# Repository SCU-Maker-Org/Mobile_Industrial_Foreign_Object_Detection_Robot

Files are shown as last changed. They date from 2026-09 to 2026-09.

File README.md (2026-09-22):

# 移动式工业异物检测机器人（履带式）

面向"机器人异物检测专项赛"的履带式自主巡检机器人。机器人在模拟核电站室内巡检环境中完全自主运行，完成对工具类、零件类、杂物类和泄漏物类异物的检测，并提交结构化检测报告。

## 机器人平台

- **底盘形式**：履带式，适应室内复杂地面与局部暗区环境
- **运行方式**：完全自主巡检，无需人工干预
- **导航能力**：支持自主导航与建图，可在赛前基准扫描阶段对场地建模
- **感知传感器**：配备 RGB 相机，可选配深度相机、热成像仪等
- **视觉检测**：基于 YOLO 的异物检测，支持双目视觉进行深度感知与三维定位

## 核心功能

| 功能 | 说明 |
|---|---|
| 自主建图与导航 | 赛前对基准场景建模，比赛中自主规划巡检路径 |
| 异物检出 | 检测工具类、零件类、杂物类、泄漏物类异物 |
| 异物分类 | 按工具类、零件类、杂物类、泄漏物类四类输出 |
| 异物定位 | 输出异物平面位置坐标，支持厘米级定位 |
| 误报控制 | 区分真实异物与设备、管道、地面纹理、阴影等背景干扰 |
| 检测报告 | 输出异物编号、类别、位置坐标、置信度和检测时间 |
| 光照适应 | 适应正常照明与局部暗区两种光照条件 |
| 遮挡适应 | 应对设备柜、管道阀门、电缆槽、基座和遮挡板形成的遮挡关系 |

## 工作流程

```text
基准扫描建图 → 自主巡检 → 异物检测 → 分类与定位 → 生成检测报告

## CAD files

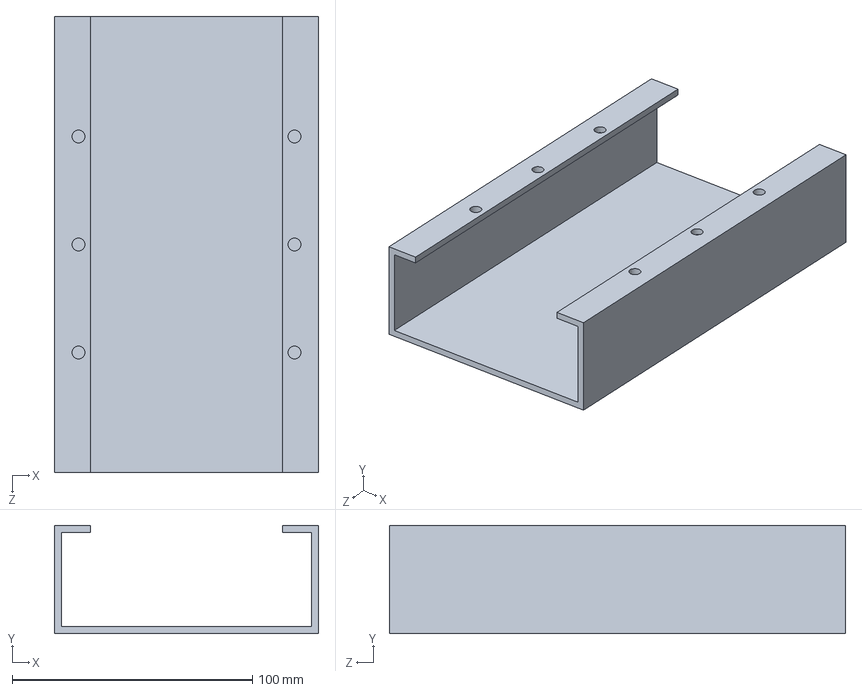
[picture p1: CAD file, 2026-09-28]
3D_Files/solidworks/底盘电池支架.SLDPRT
110.0 x 45.0 x 190.0 mm

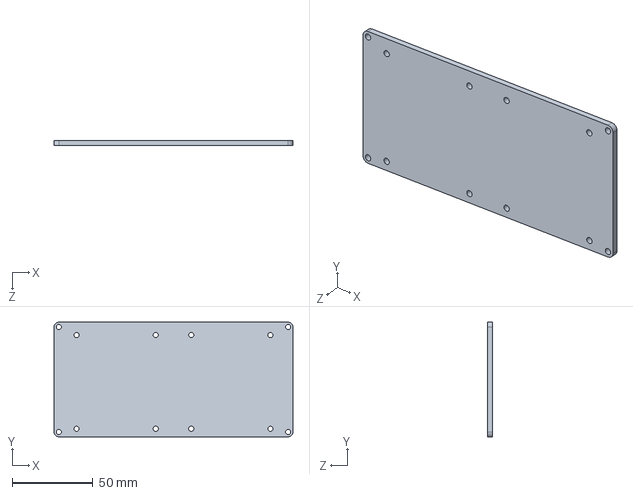
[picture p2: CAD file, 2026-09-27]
3D_Files/solidworks/树莓派和香橙派支架.SLDPRT
148.0 x 71.0 x 3.00 mm

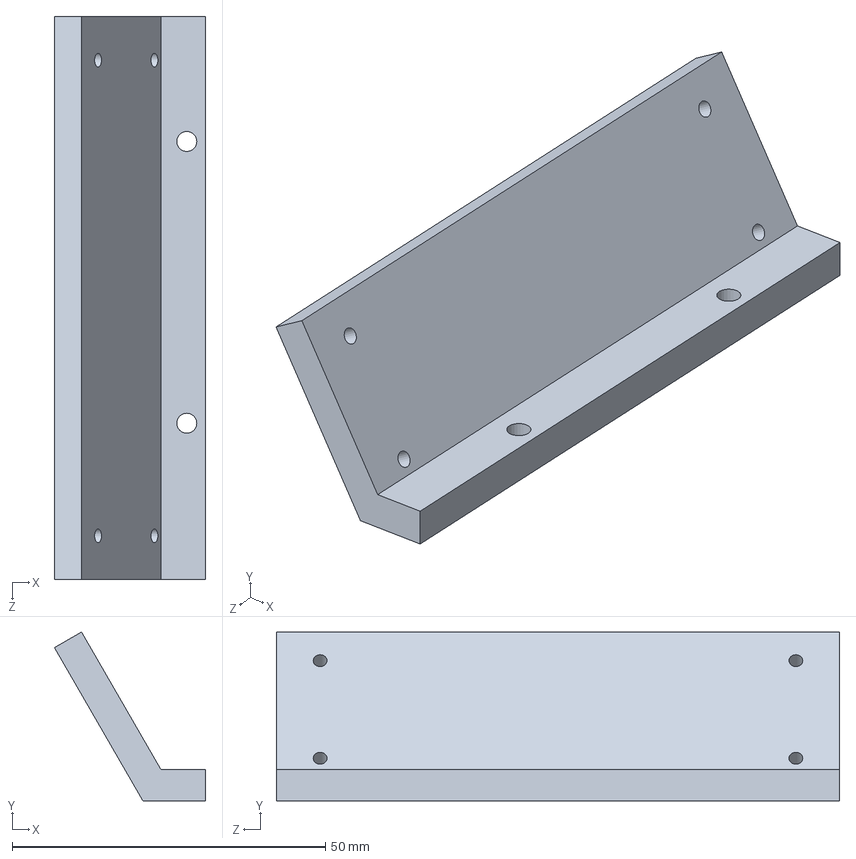
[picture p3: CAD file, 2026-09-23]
3D_Files/solidworks/双目相机支架-2.SLDPRT
24.1 x 27.0 x 90.0 mm

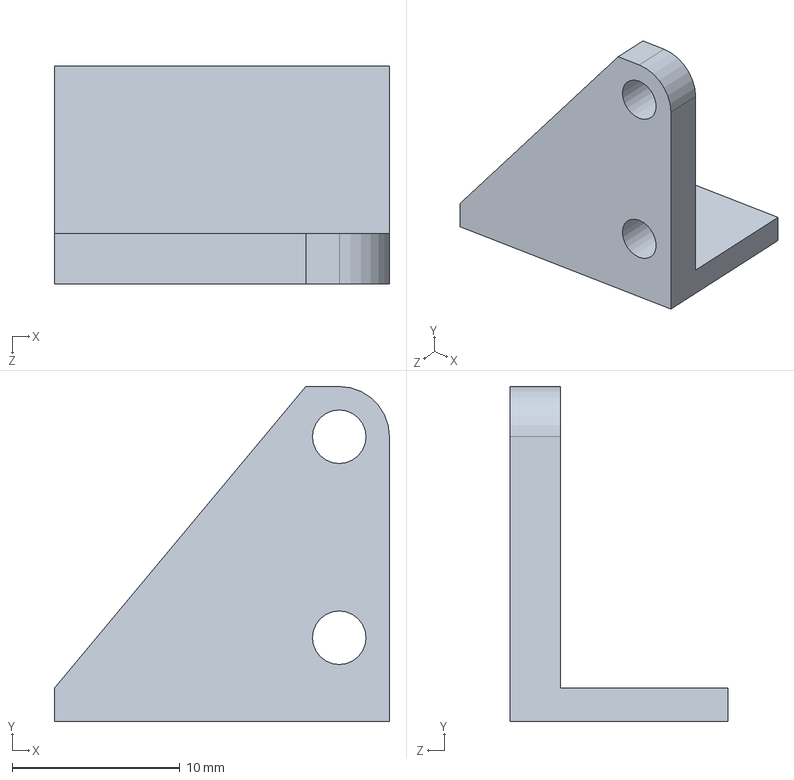
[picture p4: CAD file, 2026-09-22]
3D_Files/solidworks/LED灯带支撑件（右侧）.SLDPRT
20.0 x 20.0 x 13.0 mm

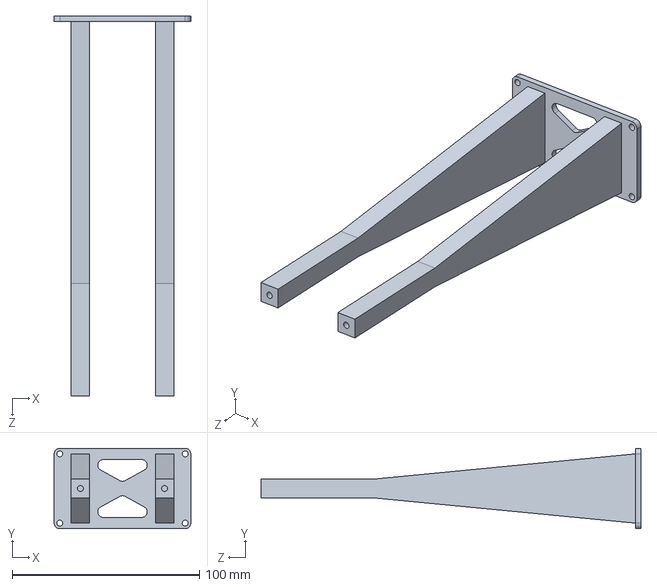
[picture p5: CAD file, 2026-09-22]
3D_Files/solidworks/双目相机支架-1.SLDPRT
73.0 x 43.0 x 203.0 mm

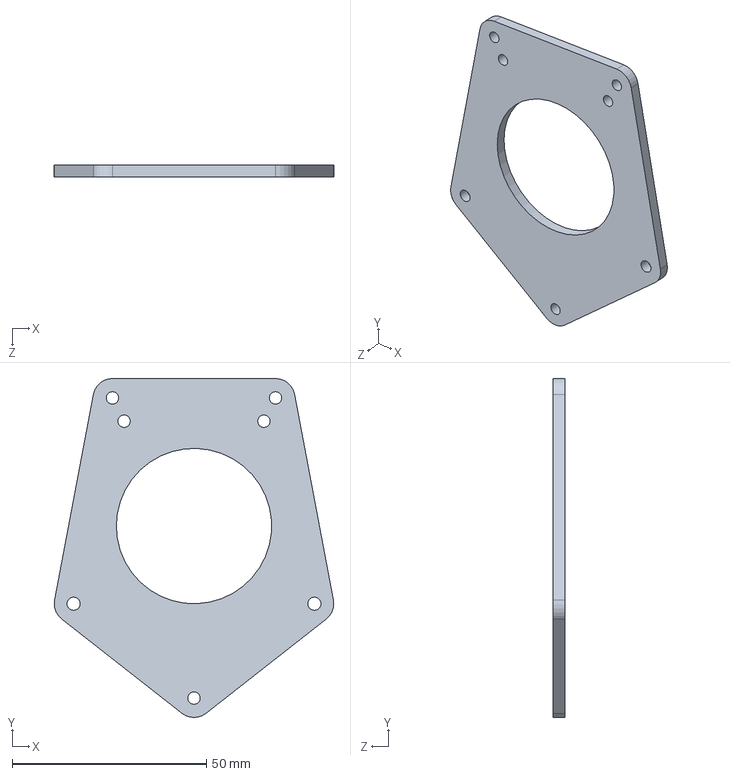
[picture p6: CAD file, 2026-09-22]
3D_Files/solidworks/激光雷达支架.SLDPRT
72.0 x 87.3 x 3.00 mm

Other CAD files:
3D_Files/solidworks/LED灯带支撑件（左侧）.SLDPRT
3D_Files/stl/LED灯带支撑件（右侧）.STL
3D_Files/stl/LED灯带支撑件（左侧）.STL
3D_Files/stl/双目相机支架-1.STL
3D_Files/stl/双目相机支架-2.STL
3D_Files/stl/底盘电池支架.STL
3D_Files/stl/树莓派和香橙派支架.STL
3D_Files/stl/激光雷达支架.STL

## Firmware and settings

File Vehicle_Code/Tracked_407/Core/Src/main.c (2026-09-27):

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
/* Includes ------------------------------------------------------------------*/
#include "main.h"
#include "tim.h"
#include "usart.h"
#include "gpio.h"

/* USER CODE BEGIN Includes */
#include "Tracked.h"
#include <stdio.h>
#include <string.h>
#include "oled.h"
#include "IMU406.h"
#include "alarm.h"
/* USER CODE END Includes */


/* USER CODE BEGIN PV */
char oled_buf[32];
/* USER CODE END PV */

void SystemClock_Config(void);
/* USER CODE BEGIN PFP */
void OLED_Show_Current_Speed(void);
void OLED_Show_Target_Speed(void);
void OLED_Show_Yaw(void);
/* USER CODE END PFP */

/**
  * @brief  The application entry point.
  * @retval int
  */
int main(void)
{

  /* MCU Configuration--------------------------------------------------------*/

  /* Reset of all peripherals, Initializes the Flash interface and the Systick. */
  HAL_Init();

  /* Configure the system clock */
  SystemClock_Config();

  /* Initialize all configured peripherals */
  MX_GPIO_Init();
  MX_TIM2_Init();
  MX_TIM3_Init();
  MX_TIM4_Init();
  MX_TIM5_Init();
  MX_USART3_UART_Init();
  MX_TIM1_Init();
  MX_TIM9_Init();
  MX_TIM10_Init();
  MX_TIM11_Init();
  MX_USART2_UART_Init();
  MX_USART1_UART_Init();
  /* USER CODE BEGIN 2 */
  /* 初始化 OLED */
  OLED_Init();
  OLED_Clear();

  /* 初始化履带底盘 */
  Tracked_Init();

  /* 启动 YOLO 串口接收 */
  YOLO_UART_Start();

  /* 系统完成初始化提示 */
  System_Init_Alarm();
  /* USER CODE END 2 */

  /* Infinite loop */
  /* USER CODE BEGIN WHILE */
  while (1)
  {

    // 找到物体后则进行报警
    if (g_yolo_object_found_flag) {
      g_yolo_object_found_flag = 0;
      Object_Found_Alarm();
    }

    // OLED显示内容
    OLED_Clear();
    OLED_Show_Current_Speed();
    OLED_Show_Target_Speed();
    OLED_Show_Yaw();
    HAL_Delay(100);


    /* USER CODE END WHILE */

    /* USER CODE BEGIN 3 */
  }
  /* USER CODE END 3 */
}

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
/* USER CODE BEGIN 4 */
void OLED_Show_Current_Speed(void)
{
  /* L:xxxx R:xxxx 共 16 字符，%-4d 左对齐补空格 */
  sprintf(oled_buf, "L:%-4d R:%-4d",
          (int)g_tracked.delta_left_cnt,
          (int)g_tracked.delta_right_cnt);
  OLED_ShowString(0, 0, (unsigned char *)oled_buf);
}

void OLED_Show_Target_Speed(void)
{
  int v_i = (int)(g_tracked.target_v);
  int v_f = (int)((g_tracked.target_v - v_i) * 100);
  if (v_f < 0) v_f = -v_f;

  int w_i = (int)(g_tracked.target_w);
  int w_f = (int)((g_tracked.target_w - w_i) * 100);
  if (w_f < 0) w_f = -w_f;

  /* Vt:x.xx Wt:x.xx 共 16 字符，长度固定 */
  sprintf(oled_buf, "Vt:%d.%02d Wt:%d.%02d",
          v_i, v_f, w_i, w_f);
  OLED_ShowString(0, 1, (unsigned char *)oled_buf);
}

void OLED_Show_Yaw(void)
{
  int32_t yaw = IMU406_Get_Yaw();
  int yaw_i = (int)(yaw / 100);
  int yaw_f = (int)(yaw % 100);
  if (yaw_f < 0) yaw_f = -yaw_f;

  /* yaw:xxx.x 后面补 6 个空格，保证总长 16 字符 */
  sprintf(oled_buf, "yaw:%d.%d      ", yaw_i, yaw_f / 10);
  OLED_ShowString(0, 2, (unsigned char *)oled_buf);
}
/* USER CODE END 4 */
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


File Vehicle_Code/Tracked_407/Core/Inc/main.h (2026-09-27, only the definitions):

#define Motor_B_IN1_Pin GPIO_PIN_5
#define Motor_B_IN1_GPIO_Port GPIOE
#define Motor_B_IN2_Pin GPIO_PIN_6
#define Motor_B_IN2_GPIO_Port GPIOE
#define Motor_C_Encoder_A_Pin GPIO_PIN_0
#define Motor_C_Encoder_A_GPIO_Port GPIOA
#define Motor_C_Encoder_B_Pin GPIO_PIN_1
#define Motor_C_Encoder_B_GPIO_Port GPIOA
#define IMU406_TX_Pin GPIO_PIN_2
#define IMU406_TX_GPIO_Port GPIOA
#define IMU406_RX_Pin GPIO_PIN_3
#define IMU406_RX_GPIO_Port GPIOA
#define HEAD_LED_Pin GPIO_PIN_5
#define HEAD_LED_GPIO_Port GPIOC
#define BLUE_LED_Pin GPIO_PIN_8
#define BLUE_LED_GPIO_Port GPIOE
#define Motor_C_IN2_Pin GPIO_PIN_9
#define Motor_C_IN2_GPIO_Port GPIOE
#define Motor_C_IN1_Pin GPIO_PIN_11
#define Motor_C_IN1_GPIO_Port GPIOE
#define Motor_D_IN2_Pin GPIO_PIN_13
#define Motor_D_IN2_GPIO_Port GPIOE
#define Motor_D_IN1_Pin GPIO_PIN_14
#define Motor_D_IN1_GPIO_Port GPIOE
#define USART3_ROS_TX_Pin GPIO_PIN_8
#define USART3_ROS_TX_GPIO_Port GPIOD
#define USART3_ROS_RX_Pin GPIO_PIN_9
#define USART3_ROS_RX_GPIO_Port GPIOD
#define OLED_DC_Pin GPIO_PIN_11
#define OLED_DC_GPIO_Port GPIOD
#define OLED_RES_Pin GPIO_PIN_12
#define OLED_RES_GPIO_Port GPIOD
#define OLED_SDA_Pin GPIO_PIN_13
#define OLED_SDA_GPIO_Port GPIOD
#define OLED_SCL_Pin GPIO_PIN_14
#define OLED_SCL_GPIO_Port GPIOD
#define BEEP_Pin GPIO_PIN_8
#define BEEP_GPIO_Port GPIOA
#define YOLO_TX_Pin GPIO_PIN_9
#define YOLO_TX_GPIO_Port GPIOA
#define YOLO_RX_Pin GPIO_PIN_10
#define YOLO_RX_GPIO_Port GPIOA
#define Motor_A_Encoder_A_Pin GPIO_PIN_15
#define Motor_A_Encoder_A_GPIO_Port GPIOA
#define Motor_A_Encoder_B_Pin GPIO_PIN_3
#define Motor_A_Encoder_B_GPIO_Port GPIOB
#define Motor_B_Encoder_A_Pin GPIO_PIN_4
#define Motor_B_Encoder_A_GPIO_Port GPIOB
#define Motor_B_Encoder_B_Pin GPIO_PIN_5
#define Motor_B_Encoder_B_GPIO_Port GPIOB
#define Motor_D_Encoder_A_Pin GPIO_PIN_6
#define Motor_D_Encoder_A_GPIO_Port GPIOB
#define Motor_D_Encoder_B_Pin GPIO_PIN_7
#define Motor_D_Encoder_B_GPIO_Port GPIOB
#define Motor_A_IN2_Pin GPIO_PIN_8
#define Motor_A_IN2_GPIO_Port GPIOB
#define Motor_A_IN1_Pin GPIO_PIN_9
#define Motor_A_IN1_GPIO_Port GPIOB

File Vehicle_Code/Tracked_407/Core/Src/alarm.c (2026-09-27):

//
// alarm.c
// 报警 + YOLO 串口接收实现
//

#include "alarm.h"

/* ================================================================== */
/*                     全局标志                                        */
/* ================================================================== */
volatile uint8_t g_yolo_object_found_flag = 0;

/* ================================================================== */
/*                    YOLO 接收私有变量                                 */
/* ================================================================== */
static uint8_t  s_yolo_rx_byte = 0;
static uint8_t  s_yolo_frame[YOLO_FRAME_LEN];
static uint8_t  s_yolo_index = 0;

/* ================================================================== */
/*                        报警函数实现                                  */
/* ================================================================== */
void System_Init_Alarm(void)
{
    for (int i = 0; i < SYSTEM_INIT_ALARM_TIMES; i++) {
        HAL_GPIO_WritePin(BEEP_GPIO_Port, BEEP_Pin, GPIO_PIN_SET);
        HAL_GPIO_WritePin(BLUE_LED_GPIO_Port, BLUE_LED_Pin, GPIO_PIN_SET);
        HAL_Delay(200);
        HAL_GPIO_WritePin(BEEP_GPIO_Port, BEEP_Pin, GPIO_PIN_RESET);
        HAL_GPIO_WritePin(BLUE_LED_GPIO_Port, BLUE_LED_Pin, GPIO_PIN_RESET);
        HAL_Delay(200);
    }
}

void Object_Found_Alarm(void)
{
    for (int i = 0; i < OBJECT_FOUND_ALAEM_TIMES; i++) {
        HAL_GPIO_WritePin(BEEP_GPIO_Port, BEEP_Pin, GPIO_PIN_SET);
        HAL_GPIO_WritePin(BLUE_LED_GPIO_Port, BLUE_LED_Pin, GPIO_PIN_SET);
        HAL_Delay(100);
        HAL_GPIO_WritePin(BEEP_GPIO_Port, BEEP_Pin, GPIO_PIN_RESET);
        HAL_GPIO_WritePin(BLUE_LED_GPIO_Port, BLUE_LED_Pin, GPIO_PIN_RESET);
        HAL_Delay(100);
    }
}

/* ================================================================== */
/*                    YOLO 帧解析（私有）                               */
/* ================================================================== */
/**
 * @brief YOLO 逐字节解析
 * @note  协议: [0xAA] [cmd] [param] [checksum]
 *        checksum = byte0 ^ byte1 ^ byte2
 */
static void YOLO_ParseByte(uint8_t byte)
{
    /* 帧头对齐 */
    if (s_yolo_index == 0U) {
        if (byte != YOLO_FRAME_HEAD) {
            return;
        }
    }

    s_yolo_frame[s_yolo_index++] = byte;

    if (s_yolo_index >= YOLO_FRAME_LEN) {
        s_yolo_index = 0U;

        /* 校验和 */
        uint8_t sum = s_yolo_frame[0] ^ s_yolo_frame[1] ^ s_yolo_frame[2];
        if (sum != s_yolo_frame[3]) {
            return;
        }

        /* 只处理"检测到物体"命令 */
        if (s_yolo_frame[1] == YOLO_CMD_OBJECT_FOUND) {
            g_yolo_object_found_flag = 1;    /* 只置标志，不报警 */
        }
    }
}

/* ================================================================== */
/*                    YOLO 公共接口实现                                 */
/* ================================================================== */
void YOLO_UART_Start(void)
{
    s_yolo_index = 0;
    HAL_UART_Receive_IT(YOLO_UART, &s_yolo_rx_byte, 1);
}

void YOLO_RxHandler(void)
{
    /* 解析当前字节 */
    YOLO_ParseByte(s_yolo_rx_byte);
    /* 重新开启接收 */
    HAL_UART_Receive_IT(YOLO_UART, &s_yolo_rx_byte, 1);
}

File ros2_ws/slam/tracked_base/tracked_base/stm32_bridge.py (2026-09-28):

#!/usr/bin/env python3
# -*- coding: utf-8 -*-
"""
STM32 双向串口桥接节点

上行 (STM32 -> ROS2, USART3, 230400):
  - 里程计帧 type=0x01  长度 28
  - IMU 帧   type=0x02  长度 36

下行 (ROS2 -> STM32):
  - /cmd_vel            -> 13 字节帧, type=0x01
  - /tracked/reset_odom -> 13 字节帧, type=0x03

校验：XOR（与 Tracked.c 中 Tracked_Checksum 一致）
"""

import math
import struct
import threading
import time

import rclpy
from rclpy.node import Node
from rclpy.qos import QoSProfile, ReliabilityPolicy, HistoryPolicy

import serial

from geometry_msgs.msg import Twist, TransformStamped
from nav_msgs.msg import Odometry
from sensor_msgs.msg import Imu
from std_srvs.srv import Trigger
from tf2_ros import TransformBroadcaster


# ============================================================
# 协议常量（与 Tracked.h 严格一致）
# ============================================================
UP_HEAD0 = 0xAA
UP_HEAD1 = 0x55
UP_TYPE_ODOM = 0x01
UP_TYPE_IMU  = 0x02

CMD_HEAD0       = 0xAA
CMD_HEAD1       = 0x55
CMD_TYPE_VEL    = 0x01
CMD_TYPE_RESET  = 0x03
CMD_TAIL        = 0x0D
CMD_FRAME_LEN   = 13

ODOM_FRAME_LEN = 28
IMU_FRAME_LEN  = 36


def xor_checksum(data: bytes) -> int:
    s = 0
    for b in data:
        s ^= b
    return s


def euler_to_quaternion(roll, pitch, yaw):
    cy = math.cos(yaw * 0.5)
    sy = math.sin(yaw * 0.5)
    cp = math.cos(pitch * 0.5)
    sp = math.sin(pitch * 0.5)
    cr = math.cos(roll * 0.5)
    sr = math.sin(roll * 0.5)
    qw = cr * cp * cy + sr * sp * sy
    qx = sr * cp * cy - cr * sp * sy
    qy = cr * sp * cy + sr * cp * sy
    qz = cr * cp * sy - sr * sp * cy
    return qx, qy, qz, qw


class STM32Bridge(Node):

    def __init__(self):
        super().__init__('stm32_bridge')

        # -------- 参数 --------
        self.declare_parameter('port', '/dev/motor')
        self.declare_parameter('baudrate', 230400)
        self.declare_parameter('odom_frame', 'odom')
        self.declare_parameter('base_frame', 'base_footprint')
        self.declare_parameter('imu_frame',  'imu_link')
        self.declare_parameter('publish_tf', False)
        self.declare_parameter('cmd_vel_topic', 'cmd_vel')

        port     = self.get_parameter('port').value
        baudrate = self.get_parameter('baudrate').value
        self.odom_frame = self.get_parameter('odom_frame').value
        self.base_frame = self.get_parameter('base_frame').value
        self.imu_frame  = self.get_parameter('imu_frame').value
        self.publish_tf = self.get_parameter('publish_tf').value
        cmd_topic       = self.get_parameter('cmd_vel_topic').value

        # -------- QoS --------
        sensor_qos = QoSProfile(
            reliability=ReliabilityPolicy.BEST_EFFORT,
            history=HistoryPolicy.KEEP_LAST,
            depth=20
        )

        # -------- 发布者 --------
        self.pub_odom = self.create_publisher(Odometry, 'odom_raw', sensor_qos)
        self.pub_imu  = self.create_publisher(Imu, 'imu/data_raw', sensor_qos)

        # -------- 订阅者 --------
        self.create_subscription(Twist, cmd_topic, self.cmd_vel_callback, 10)

        # -------- 清零 service --------
        self.create_service(Trigger, '/tracked/reset_odom', self.handle_reset_odom)

        # -------- TF --------
        if self.publish_tf:
            self.tf_broadcaster = TransformBroadcaster(self)

        # -------- 串口 --------
        try:
            self.ser = serial.Serial(
                port=port, baudrate=baudrate,
                bytesize=serial.EIGHTBITS,
                parity=serial.PARITY_NONE,
                stopbits=serial.STOPBITS_ONE,
                timeout=0.05
            )
            self.get_logger().info(f'串口已打开: {port} @ {baudrate}')
        except serial.SerialException as e:
            self.get_logger().error(f'串口打开失败: {e}')
            raise

        # -------- 状态 --------
        self.buf = bytearray()
        self.running = True
        self.write_lock = threading.Lock()

        self.odom_count = 0
        self.imu_count = 0
        self.err_count = 0

        # -------- 读线程 --------
        self.rx_thread = threading.Thread(target=self.rx_loop, daemon=True)
        self.rx_thread.start()

        # -------- 统计定时器 --------
        self.create_timer(5.0, self.stats_callback)

        self.get_logger().info('=' * 50)
        self.get_logger().info('STM32 Bridge 已启动')
        self.get_logger().info(f'  port       = {port} @ {baudrate}')
        self.get_logger().info(f'  odom_frame = {self.odom_frame}')
        self.get_logger().info(f'  base_frame = {self.base_frame}')
        self.get_logger().info(f'  imu_frame  = {self.imu_frame}')
        self.get_logger().info(f'  publish_tf = {self.publish_tf}')
        self.get_logger().info(f'  cmd_vel    = {cmd_topic}')
        self.get_logger().info('  reset      = /tracked/reset_odom (Trigger)')
        self.get_logger().info('=' * 50)

    # ============================================================
    def rx_loop(self):
        while self.running and rclpy.ok():
            try:
                n = self.ser.in_waiting
                if n > 0:
                    data = self.ser.read(n)
                    self.buf.extend(data)
                    self.parse_buffer()
                else:
                    time.sleep(0.002)
            except serial.SerialException as e:
                self.get_logger().error(f'串口读取异常: {e}')
                time.sleep(0.5)
            except Exception as e:
                self.get_logger().error(f'RX 异常: {e}')
                time.sleep(0.5)

    # ============================================================
    def parse_buffer(self):
        while True:
            if len(self.buf) < 3:
                return
            idx = self.buf.find(bytes([UP_HEAD0, UP_HEAD1]))
            if idx < 0:
                if len(self.buf) > 1:
                    self.buf = self.buf[-1:]
                return
            if idx > 0:
                self.buf = self.buf[idx:]
            if len(self.buf) < 3:
                return

            ftype = self.buf[2]
            if ftype == UP_TYPE_ODOM:
                flen = ODOM_FRAME_LEN
            elif ftype == UP_TYPE_IMU:
                flen = IMU_FRAME_LEN
            else:
                self.buf = self.buf[1:]
                continue

            if len(self.buf) < flen:
                return
            frame = bytes(self.buf[:flen])

            if xor_checksum(frame[:-1]) != frame[-1]:
                self.err_count += 1
                self.buf = self.buf[1:]
                continue

            if ftype == UP_TYPE_ODOM:
                self.handle_odom(frame)
            else:
                self.handle_imu(frame)
            self.buf = self.buf[flen:]

    # ============================================================
    def handle_odom(self, frame: bytes):
        (_hdr, _type,
         x, y, yaw, v, w,
         _ts, _chk) = struct.unpack('<2sBfffffIB', frame)
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

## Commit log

2026-09-22 Add README
    [双目相机支架-1.SLDPRT, 双目相机支架-1.STL, 双目相机支架-2.SLDPRT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]
2026-09-22 创建STM32F103C8T6驱动底盘运动工程
    [LED灯带支撑件（右侧）.SLDPRT, LED灯带支撑件（右侧）.STL, LED灯带支撑件（左侧）.SLDPRT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]
2026-09-22 [日结]2026.09.22 StrayerSQH：将STM32引脚进行分配和用户命名，等待编写正式代码
2026-09-23 2026-09-23 更新：修改双目相机支架-2（调整L型结构夹角以及螺丝孔）
    [双目相机支架-2.SLDPRT, 双目相机支架-2.STL]
2026-09-23 2026-09-23 更新：代码
2026-09-24 更新：更新小车代码（但是手上的TB6612芯片发生了损坏，经商议后决定将STM32F103系列芯片替换为STM32F407系列芯片重建工程
2026-09-24 更新：弃用F103版本代码，保留以防万一
2026-09-24 更新：将之前写的ROS2代码在openEuler上验证。验证结果表示SLAM部分激光雷达测量信息能够被正常加载；SLAM建图功能能够正常启动。需要作的工作如下：1.继续编写小车底盘端的代码，将正运动学信息融合IMU数据发送至ROS端；2.SLAM建图需要将部分激光雷达扫描的角度删除。
2026-09-26 更新：1.成功将代码迁移到STM32F407；2.验证电机功能并确定正常；3.验证闭环调速正常，小车能按照给定的v和w进行电机调速 代办：1.调节PID参数（先保证电机的响应没问题）2.将IMU406连线到开发板并验证数据读取功能；3.画下层将电池固定与底盘下层；4.画上层将驱动板叠层安装（具体为电机驱动板放在最下层树莓派和香橙派放在上层）
2026-09-27 增加视觉YOLO工作区
2026-09-27 更新：1.完成PID调参；2.通过本地PC完成对串口3上行帧和下行帧的发送验证；3.增加系统启动提示。 代办：1.通过本地PC完成对串口1下行帧的发送验证；2.ROS
2026-09-27 更新：1.通过查看USB设备的唯一标识，将激光雷达和小车驱动板分别映射到唯一的/dev/....； 2.将激光雷达节点的启动代码分别移动到SLAM和nav中
2026-09-27 将 ros2_ws/CAAIROBOT_2026 从 gitlink 转为普通文件夹
2026-09-27 更新：1.增加.gitignore；2.增加SLAM建图部分的代码
2026-09-28 ROS更新：1.验证并通过修改源文件的形式将遥控小车的速度进行了修改，确保了遥控功能能够正常实现；2.增加/scan_filter话题来过滤激光雷达0-45度和315-360度的激光雷达数据
2026-09-28 底盘更新：1.将小车的IMU406传感器进行上电归零操作；2.修改小车UART3中断接收程序，使之能够对ROS端启动slam时下发的odom归零进行响应。 代办：1.修改小车硬件电路让IMU406传感器提前于小车代码的启动，不然IMU406传感器会造成一定的零漂导致ROS端的imu相关话题有误差
    [底盘电池支架.SLDPRT]

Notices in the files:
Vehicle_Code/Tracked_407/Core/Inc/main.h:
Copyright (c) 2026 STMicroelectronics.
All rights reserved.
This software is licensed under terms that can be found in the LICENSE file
